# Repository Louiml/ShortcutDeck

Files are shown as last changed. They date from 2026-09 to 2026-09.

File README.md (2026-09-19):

# ShortcutDeck

A 6-button shortcut controller built on an Arduino Uno R3. Each button has its
own OLED label. A cross-platform Electron app on your PC customizes each button
to launch an app, file, or URL, or run a Lua script.

```
 OLED0  OLED1  OLED2         Arduino Uno R3
 [B0]   [B1]   [B2]   -+     +- TCA9548A (6x OLED I2C)
 OLED3  OLED4  OLED5   +USB- +-- 6x tactile buttons D2..D7
 [B3]   [B4]   [B5]   -+     +-- USB serial (115200)

 Electron companion app on your PC
 (GUI config + Lua sandbox + app launching)
```

## Repository layout

| Path | Purpose |
|---|---|
| `requirements.md` | Bill of materials, tools, system requirements |
| `circuit-schematic/`  | Wiring, schematic, component design, 3D case |
| `arduino/` | Firmware and serial protocol |
| `app/` | Electron companion app |

## Quick start

### 1. Electronics

Follow `circuit-schematic/wiring-diagram.md` to wire the Uno, TCA9548A, six
OLEDs, and six buttons. See `schematic.md` and `component-design.md` for layout,
power, and I2C addressing.

### 2. Firmware

Install the Adafruit SSD1306 and Adafruit GFX libraries. Open
`arduino/ShortcutDeck/ShortcutDeck.ino`, pick your port and board, and upload.
The deck sends `RDY` over serial at 115200 once it is up.

### 3. Companion app

```
cd app
npm install
npm start
```

Connect the deck, then edit and save button config. See `app/README.md`.

## Documentation

- `requirements.md` describes what to buy and install.
- `arduino/PROTOCOL.md` documents the serial protocol.
- `app/README.md` covers running the app, Lua scripting, and testing.

## License

MIT.

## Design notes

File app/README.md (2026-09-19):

# ShortcutDeck companion app

A cross-platform desktop app that works with the Arduino ShortcutDeck firmware.

## Features

- Configure all six buttons from one GUI.
  - Label shown on the button's OLED.
  - Icon (5 built-in glyphs, or none).
  - Action of none, launch (app, file, folder, or URL), or a Lua script.
- When the Arduino is connected, labels and icons push to the OLEDs automatically.
- Button presses arrive over USB serial and trigger the configured action.
- Lua scripts run sandboxed (via fengari) with a safe `deck` API.
- Config is saved locally and restored on each launch.

## Requirements

- Node.js 18+ for development.
- A CH340 driver if you use a clone Uno. Originals need none.

## Install and run

```
cd app
npm install
npm start
```

On some Linux systems the `serialport` native module needs build tools. `npm
install` usually fetches a prebuilt binary. If not, install `build-essential`
and `python3` and retry.

## Tests

```
npm test
```

This runs the Lua sandbox smoke test.

## Project layout

```
app/
|-- package.json
+-- src/
    |-- main/
    |   |-- main.js            Electron main process, IPC, wiring
    |   |-- configStore.js     persists button config to userData
    |   |-- serialManager.js   USB serial to the Arduino
    |   |-- luaRunner.js       sandboxed Lua execution (fengari)
    |   |-- launcher.js        cross-platform open and launch
    |   +-- test-lua.js        Lua sandbox smoke test
    +-- renderer/
        |-- index.html         GUI markup
        |-- style.css          GUI styling, dark theme
        +-- renderer.js        GUI logic and IPC calls
```

## Usage

1. Flash the Arduino. See `../arduino/ShortcutDeck/ShortcutDeck.ino`.
2. Plug in the Uno and launch the app.
3. In the Connect bar, pick the serial port and press Connect.
4. On connect, the current config pushes to the OLEDs (RDY handshake).
5. Edit any button card, then press Save & Apply to Deck.
6. Press a physical button. The app runs its action and logs it in the side
   panel.

## Lua scripting

Write Lua in any button with action set to Lua. The API:

```lua
deck.print("anything", 1, true)   -- log a line in the app log
deck.open("https://youtube.com")  -- open via the OS default handler
deck.exec("taskmgr.exe")          -- run a shell command, async
```

Sandbox restrictions:

- No `io`, `os.execute`, `os.exit`, filesystem, or network access.
- Only a curated global set is available: `table`, `string`, `math`, `os`
  (minus unsafe functions), `pairs`, `ipairs`, `pcall`, `error`, and so on.
- Scripts run on every button press.

## Notes

- Serial baud is fixed at 115200, matching the firmware.
- Labels cannot contain the pipe character. It is the protocol field separator.
- If you change the Lua code to reach the filesystem, you are expanding the
  sandbox. Keep it locked down.

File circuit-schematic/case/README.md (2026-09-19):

# Case design

Parametric OpenSCAD source: `deck_case.scad`

This renders a 2 by 3, two-piece snap-together enclosure.

- The top plate holds the six OLED windows and the six button bezels.
- The bottom base forms the cavity that holds the Arduino Uno, the TCA9548A
  breakout, and a rear USB opening.

## Files

| File | Description |
|---|---|
| `deck_case.scad` | Parametric source. Adjust the constants at the top. |
| `deck_case_top.stl` | Pre-rendered top plate. Open in a slicer. |
| `deck_case_bottom.stl`  | Pre-rendered bottom base. |

Ready-to-print STLs are included. To re-render after changing the source, use
the commands below. Adjust the OpenSCAD path if it is not in Program Files.

## Generating the STL files

You need [OpenSCAD](https://openscad.org/). Run this to export the parts:

```powershell
& "C:\Program Files\OpenSCAD\openscad.exe" deck_case.scad -D "part=0" -o deck_case_top.stl
& "C:\Program Files\OpenSCAD\openscad.exe" deck_case.scad -D "part=1" -o deck_case_bottom.stl
```

On macOS or Linux, adjust the path: `openscad deck_case.scad -D part=0 -o ...`.

## Print settings

- Material: PLA or PETG.
- Layer height: 0.2 mm.
- Infill: about 20%, with three or more top and bottom walls.
- Brim: recommended on the bottom base so the tall cavity walls stick.
- Orientation: print the top plate face down, floor up.

## Dimensions

| Item | Value |
|---|---|
| OLED breakout board | 27 by 27 by 9 mm recess|
| Visible OLED glass | 22 by 12 mm window |
| Tactile button | 12 mm diameter hole |
| Button pitch, X | 36 mm |
| Row pitch, Y | 42 mm |
| Case wall | 2.5 mm |
| Case height | 16 mm |
| USB-B port opening | 13 by 8 mm, rear wall  |

## Assembly

1. Drop each OLED in its top-plate recess, glass facing up. Tack it with a dab
   of hot glue or an M2 screw through the screw bosses.
2. Snip or place the tactile buttons so they stick through the 12 mm holes.
3. Wire everything to the Arduino (see `schematic.md`) and drop the Uno into the
   bottom cavity with its USB-B port lined up with the rear-wall opening, so the
   cable plugs in from outside.
4. Route the USB cable through the rear opening. Run six wires, SDA, SCL, 5V,
   GND, and VCC separately. Bussed headers are easier.
5. Snap the top over the bottom and secure the corners with M2 screws.

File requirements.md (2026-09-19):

# ShortcutDeck: requirements

A 6-button shortcut controller built on an Arduino Uno R3. Each button has its
own OLED label, customized from a cross-platform Electron app on the PC. Button
presses travel over USB serial to the PC, where a background app launches
apps, files, URLs, or runs user-written Lua scripts.

## Hardware

### Bill of materials

| # | Component | Qty | Notes | Est. cost |
|---|---|-----|---|---|
| 1 | Arduino Uno R3 | 1 | ATmega328P, 5V logic, 22 digital IO, 6 analog. | ~$25 |
| 2 | SSD1306 OLED 0.96" | 6 | I2C, address 0x3C. One per button. | ~$3 each  |
| 3 | TCA9548A I2C MUX | 1 | 8-channel I2C multiplexer. Selects which OLED to talk to. | ~$6 |
| 4 | Tactile push button  | 6 | 4-pin momentary switch, 12mm. | ~$0.20 |
| 5 | Resistor 10k ohm | 6 | Pull-down for each button. | ~$0.50 |
| 6 | Breadboard (830 pt)  | 1 | For prototyping. Optional if you solder to perfboard. | ~$4 |
| 7 | Jumper wires M-M | 1 | 20+ pieces, breadboard friendly. | ~$6 |
| 8 | USB A-B cable | 1 | Connects Uno to PC. Also supplies power and serial. | ~$3 |
| 9 | 3D-printed case | 1 | Optional enclosure. See `circuit-schematic/case/`. | filament  |

Total comes to about $60 to $75. You can start with a breadboard and a single
OLED to test the firmware before building all six.

### Power

- Uno USB provides 5V at 500mA (negotiated). All I2C devices are 3.3/5V tolerant.
- Each SSD1306 OLED draws roughly 15 to 25mA (20 to 30mA with backlight on).
  6 OLEDs worst case is about 120 to 150mA. That fits in the Uno USB budget.
- 6 buttons plus 6 pull-downs draw sub-milliamp, effectively nothing.
- Total draw is about 150 to 200mA. Safe on USB and on the Uno 5V regulator.

## Software and tools

| Tool | Purpose |
|---|---|
| Arduino IDE 1.8+  | Build and flash `ShortcutDeck.ino` |
| or Arduino CLI | Command-line build and flash |
| Node.js 18+ | Run the Electron app and install dependencies |
| npm | Install `electron`, `serialport`, `fengari` |
| Git | Version control |
| CH340 driver* | USB serial driver if you use a clone Uno |

*Original Arduino boards run an onboard ATmega16U2 and need no driver. Chinese
clones often use a CH340 chip and need the CH340 driver on Windows.

### Arduino libraries (Library Manager)

| Library | Purpose |
|---|---|
| Adafruit SSD1306 | SSD1306 OLED driver |
| Adafruit GFX | Graphics and text primitives for OLED |

The project cycles its own I2C channels instead of using the Adafruit
multiplexer library, to keep RAM low on the Uno's 2KB. See
`arduino/PROTOCOL.md` for details.

## I2C addressing

| Device | Address | Bus |
|---|---|---|
| TCA9548A multiplexer | 0x70 (configurable via A0-A2) | Main bus from Uno |
| Each SSD1306 OLED | 0x3C (all) | One of mux channels 0-5 |

All six OLEDs share address 0x3C because each sits on its own mux channel. You
do not need to solder address jumpers.

## System requirements

- Windows 10/11, macOS 11+, or Linux (X11/Wayland).
- Node.js 18+ is needed to run the app in development. Packaged Electron builds
  bundle Node, so end users do not need it.

## Functional requirements

1. Six physical buttons, each with an OLED showing its label and icon.
2. A button press sends `BTN:<index>` over USB serial.
3. The GUI app customizes each button:
   - Label text shown on the OLED.
   - Icon or emoji shown on the OLED.
   - Action type of launch (app/file/URL) or run a Lua script.
4. The app listens for button presses and triggers the configured action.
5. Lua scripts run in a sandboxed interpreter (fengari) with a small host API
   (open, exec, print). Scripts cannot reach the filesystem or network unless
   the bridge provides it.
6. The app saves config locally and pushes labels and icons to the Arduino, so
   the OLED labels survive restarts when the app runs.

## Out of scope for v1

- Audio routing or volume control. Could be added later as an action type.
- Multi-page button banks. The firmware only supports 6 buttons.
- Higher-resolution RGB LCDs. Would need an ESP32 or Mega.
- Hot-swapping pages over serial. Possible future feature.

## File map

```
ShortcutDeck/
|-- requirements.md
|-- circuit-schematic/
|   |-- wiring-diagram.md
|   |-- schematic.md
|   |-- component-design.md
|   +-- case/
|-- arduino/
|   |-- ShortcutDeck/ShortcutDeck.ino
|   +-- PROTOCOL.md
+-- app/
    +-- src/
        |-- main/
        +-- renderer/
```

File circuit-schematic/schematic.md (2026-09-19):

# Schematic

ASCII schematic of the ShortcutDeck electrical design.

## Block diagram

```
 Arduino Uno R3  - USB serial -  PC (Electron app)
                 |                receives BTN:n presses
                 |                sends OLED config
                 |
   I2C (SDA=A4, SCL=A5), 5V, GND
    |
    +-- 6 buttons (pull-downs) on D2..D7
    |
    +-- TCA9548A mux, channels 0-5
            |  |  |  |  |  |
          OLED0..5, one per channel, address 0x3C
```

## Full schematic

```
             ARDUINO UNO
                 5V ----+-----------------> 5V rail (OLEDs, buttons, mux)
                 GND ---+-----------------> GND rail
             A4 (SDA) --+->  TCA9548A.SDA
             A5 (SCL) --+->  TCA9548A.SCL
             D2 -> BTN0, pull-down -> GND
             D3 -> BTN1, pull-down -> GND
             D4 -> BTN2, pull-down -> GND
             D5 -> BTN3, pull-down -> GND
             D6 -> BTN4, pull-down -> GND
             D7 -> BTN5, pull-down -> GND

   TCA9548A:
     VCC GND SDA SCL  from Uno
     SD0 SC0 <-> OLED0 (0x3C)
     SD1 SC1 <-> OLED1 (0x3C)
     SD2 SC2 <-> OLED2 (0x3C)
     SD3 SC3 <-> OLED3 (0x3C)
     SD4 SC4 <-> OLED4 (0x3C)
     SD5 SC5 <-> OLED5 (0x3C)

   All six OLEDs share VCC and GND. Each OLED's SDA and SCL connect to one
   TCA9548A output pair, so they can all keep the default address 0x3C.
```

## Netlist

```
Net 5V:
   Uno.5V  -> TCA9548A.VCC, OLED0..5.VCC, BTN0..5.A

Net GND:
   Uno.GND -> TCA9548A.GND, OLED0..5.GND
            -> R0..R5 (10k pull-downs) -> BTN0..5 + D2..D7

Net I2C:
   Uno.A4 (SDA) -> TCA9548A.SDA
   Uno.A5 (SCL) -> TCA9548A.SCL

Net channel n (n = 0..5):
   TCA9548A.SDn -> OLEDn.SDA
   TCA9548A.SCn -> OLEDn.SCL

Net buttons:
   Uno.D2 -> R0 (to GND) + BTN0
   ... one per button, D3..D7 map to BTN1..BTN5
```

## Notes

Pull-ups. The TCA9548A breakout has onboard 4.7k ohm pull-ups on SDA and SCL.
If you use a bare mux chip, add your own. Each OLED branch adds none, so only
the main bus carries pull-ups.

Polarity. Some OLED modules run on 3.3V only. If yours is 5V tolerant it works
on the Uno. Most SSD1306 breakout boards accept 3.3V to 5V.

Addresses. The mux sits at 0x70 with A0, A1, and A2 all low. The OLEDs all sit
at 0x3C.

Reset. If your OLED has an RST pin, tie it high (5V) or leave it unconnected
when the module does not use it.

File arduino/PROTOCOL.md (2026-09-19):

# ShortcutDeck serial protocol

The Arduino and the Electron app talk over the Uno USB serial at 115200 baud.
Every message is ASCII text ended by a newline. A carriage return is ignored.

## Arduino to PC

| Message | Example | Meaning |
|---|---|---|
| `RDY` | `RDY` | Firmware booted, serial port is up |
| `BTN:<index>`  | `BTN:3` | Button index (0-5) was pressed |
| `OK` | `OK` | Command processed successfully |
| `ERR:<reason>` | `ERR:idx` | Command rejected (idx, cmd, argc, ...) |

`ERR` reasons:

| Reason  | Meaning |
|---|---|
| `empty` | empty line received |
| `cmd` | unknown command keyword |
| `argc`  | missing fields |
| `idx` | button index out of range (0-5) |
| `oledN` | display N failed to initialise |

## PC to Arduino

The app sends commands. The Arduino replies `OK` or `ERR:<reason>`.

| Command | Example | Meaning |
|---|---|---|
| `SET|<idx>|<icon>|<label>` | `SET|2|1|My Folder` | Set button idx label and icon |
| `CLEAR|<idx>` | `CLEAR|4` | Blank button idx (no icon or label)  |
| `PING` | `PING` | Liveness check |

### `SET` field details

- `<idx>` is a button index, an integer 0-5.
- `<icon>` is a glyph index, an integer 0-5. The mapping is:

  | Icon | Glyph   |
  |------|---------|
  | 0    | Play    |
  | 1    | Folder  |
  | 2    | Globe   |
  | 3    | Terminal|
  | 4    | Gear    |
  | 5    | Heart   |

  Use -1 for no icon.
- `<label>` is the rest of the line, up to 33 characters, shown on the OLED.
  Trailing whitespace and newlines are stripped. The label wraps to two centered
  lines on the display.

Labels may contain spaces but never the pipe character. Fields are separated by
a literal pipe, so do not put `|` in a label.

### Example exchange

```
PC -> A:  SET|0|0|YouTube
A -> PC:  OK
PC -> A:  SET|5|-1|Notes
A -> PC:  OK
A -> PC:  BTN:0        user pressed button 0
...
A -> PC:  BTN:5
PC -> A:  PING
A -> PC:  OK
```

## Notes

- Baud is fixed at 115200 in `ShortcutDeck.ino`.
- The Arduino sends `RDY` about 200 ms after boot. The app should wait for it
  before pushing config.
- Messages are small and line-buffered, so no length-prefix framing is needed.

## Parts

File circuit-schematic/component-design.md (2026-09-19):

# Component design

Layout, power budget, I2C addressing, and firmware RAM strategy for the
ShortcutDeck.

## Physical layout

A 2 by 3 grid of buttons, each with an OLED above it.

```
ShortcutDeck case
  OLED0 OLED1 OLED2       row 1 OLEDs
  B0    B1    B2          row 1 buttons
  OLED3 OLED4 OLED5       row 2 OLEDs
  B3    B4    B5          row 2 buttons
```

The Arduino, or a small perfboard with the TCA9548A, sits in the bottom of the
enclosure. A USB-B hole in the back routes the cable out.

## Power

| Load | Current |
|---|---|
| 6 SSD1306 | about 120mA |
| 6 buttons plus resistors | under 1mA |
| Arduino board | about 50mA idle  |
| TCA9548A | about 0.1mA |
| Total | about 170-200mA  |

That sits well below the Uno 500mA USB budget, so no external supply is needed.

Do not put anything else on the 5V rail that draws over 300mA total. If you add
LED backlights, budget them separately. All I2C lines stay on the 5V bus with a
shared ground.

## I2C multiplexer

The mux takes over the main bus and fans out to eight channels. We use 0 through
5.

- Main bus: Uno A4/A5 to TCA9548A SDA/SCL.
- The mux answers at 0x70 with A0, A1, and A2 grounded.
- The firmware writes one byte to the mux. Bit n set to 1 selects channel n.
- To update OLED 3, write 0x08 (channel 3) to address 0x70, then talk to the
  SSD1306 at 0x3C.
- All six OLEDs keep address 0x3C. The mux isolates each channel, so repeated
  addresses across different channels work.

Selecting channel n means calling `Wire.write(1 << n)` to address 0x70.

## Firmware RAM

The Uno has 2KB of SRAM. A full SSD1306 framebuffer is 1KB (128x64x1 bit). Six
of them would be 6KB, which will not fit. The firmware reuses one shared buffer
and cycles it across the channels, refreshing each OLED in its own time slice.

```
loop:
  for channel in 0..5:
    mux.select(channel)
    oled.drawBuffer(shared_buffer)   one reused 1KB buffer
    oled.display()
```

Because the labels and icons are static, the refresh rate does not matter. Total
RAM stays under 2KB: one 1KB buffer plus six short label strings.

If you move to an ESP32 (520KB RAM) or Mega (8KB), you can keep six independent
framebuffers and render icons or images freely.

## Icon and label rendering

Each OLED is 128 by 64 pixels.

- Row 1, pixels 0-24, holds the icon. Either a large character or a small bitmap
  glyph.
- Row 2, pixels 26-64, holds up to three lines of wrapped label text.

The firmware stores a label string and an icon per button. If the user supplies
an emoji, the default bitmap font cannot render it, since there is no unicode
glyph. The app instead picks from a set of built-in glyph bitmaps or a plain
character. See the GUI notes.

The firmware ships 24 by 24 mono glyphs for play, folder, globe, terminal, gear,
and heart, selected by index 0 through 5. The app maps the user choice to that
index and sends it over serial.

## Serial protocol summary

See `arduino/PROTOCOL.md` for the full reference. Messages are ASCII and ended
by a newline.

| Direction | Format | Purpose |
|---|---|---|
| Arduino to PC | `BTN:<0-5>` | Button pressed |
| Arduino to PC | `RDY` | Firmware ready on boot |
| Arduino to PC | `OK` / `ERR:<reason>` | Command acknowledgement |
| PC to Arduino | `SET|<idx>|<icon>|<label>` | Configure OLED label/icon  |
| PC to Arduino | `CLEAR|<idx>` | Blank an OLED |
| PC to Arduino | `PING` | Liveness check, replies OK  |

Labels are plain text. `<icon>` is an integer glyph index 0-5, or -1 for none.

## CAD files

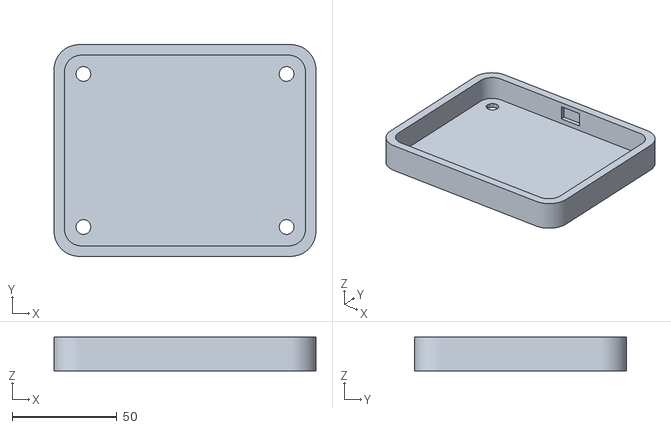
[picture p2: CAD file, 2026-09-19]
circuit-schematic/case/deck_case_bottom.stl
125.0 x 101.0 x 16.0

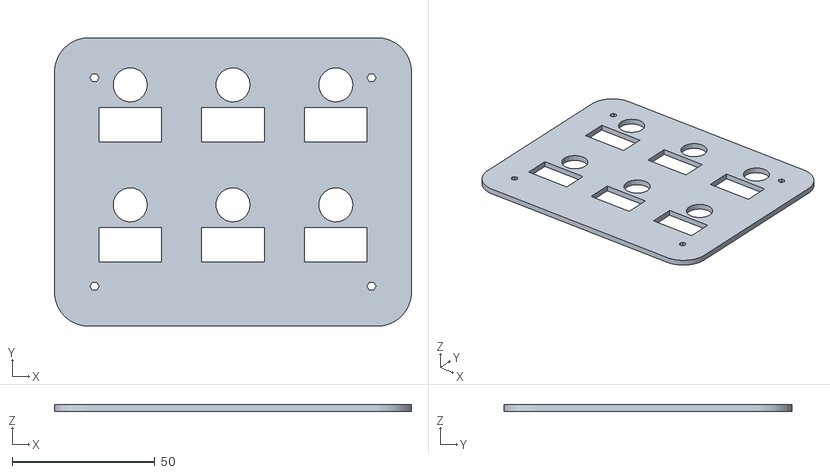
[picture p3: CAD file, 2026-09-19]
circuit-schematic/case/deck_case_top.stl
125.0 x 101.0 x 2.50

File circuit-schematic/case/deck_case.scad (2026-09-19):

deck_cols = 3;
deck_rows = 2;
spacing_x = 36;
spacing_y = 42;
oled_w    = 27;
oled_h    = 27;
glass_w   = 22;
glass_h   = 12;
btn_dia   = 12;
btn_inset = 4;

case_wall = 2.5;
case_h    = 16;
oled_ch   = 9;
btn_ch    = 4;
wall_tol  = 0.3;
screw_r   = 1.6;
screw_dx  = 8;
screw_dy  = 8;

usb_w     = 13;
usb_h     = 8;
usb_from_floor = 3;
usb_recess     = 8;

unit_cw   = spacing_x;
unit_rowA = 20;
unit_rowB = 34;
inner_w   = deck_cols * spacing_x + case_wall * 2;
inner_h   = deck_rows * spacing_y + case_wall * 2;

module rounded_square(w, h, r, $fn=48) {
    hull() {
        for (x = [r, w-r]) for (y = [r, h-r])
            translate([x, y, 0]) circle(r=r);
    }
}

module top_plate() {
    difference() {
        linear_extrude(case_wall)
            offset(r=6) rounded_square(inner_w, inner_h, 6);
        for (c=[0:deck_cols-1]) for (r=[0:deck_rows-1]) {
            let(x = case_wall + (c+0.5)*spacing_x,
                y = case_wall + r*spacing_y + unit_rowA) {
                translate([x - glass_w/2, y - glass_h/2, 0])
                    cube([glass_w, glass_h, case_wall+1]);
                translate([x - oled_w/2, y - oled_h/2, case_wall])
                    linear_extrude(oled_ch)
                        rounded_square(oled_w, oled_h, 2);
            }
        }
        for (c=[0:deck_cols-1]) for (r=[0:deck_rows-1]) {
            let(x = case_wall + (c+0.5)*spacing_x,
                y = case_wall + r*spacing_y + unit_rowB)
                translate([x, y, 0]) cylinder(d=btn_dia, h=case_wall+btn_ch+1);
        }
        for (x=[screw_dx, inner_w-screw_dx])
            for (y=[screw_dy, inner_h-screw_dy])
                translate([x, y, -1]) cylinder(d=screw_r*2, h=case_wall+3);
    }
}

module bottom_base() {
    difference() {
        union() {
            translate([0, 0, 0])
                linear_extrude(case_h - case_wall)
                    offset(r=6) rounded_square(inner_w, inner_h, 6);
            linear_extrude(case_h)
                offset(r=6) rounded_square(inner_w, inner_h, 6);
        }
        translate([case_wall+0.5, case_wall+0.5, case_wall])
            linear_extrude(case_h)
                offset(r=4) rounded_square(
                    inner_w-2*case_wall-1, inner_h-2*case_wall-1, 4);
        for (x=[screw_dx, inner_w-screw_dx])
            for (y=[screw_dy, inner_h-screw_dy])
                translate([x, y, -1]) cylinder(d=screw_r*2 + 4, h=case_h+2);
        let(ux = inner_w/2 - usb_w/2,
            uy = inner_h - usb_recess,
            uz = case_wall + usb_from_floor) {
            translate([ux, uy, uz])
                cube([usb_w, usb_recess + case_wall + 1, usb_h]);
        }
    }
}

part = 1;
if (part == 0) top_plate();
else           bottom_base();

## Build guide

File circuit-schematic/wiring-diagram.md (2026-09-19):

# Wiring diagram

Pin-by-pin wiring table for the ShortcutDeck.

## Uno to TCA9548A (main I2C bus)

| Uno pin | Function  | TCA9548A pin | Notes |
|---|---|---|---|
| A5 (SCL) D19 | I2C clock | SCL | Connect A5 to SCL. Pull-ups live on the mux board. |
| A4 (SDA) D18 | I2C data  | SDA | Connect A4 to SDA. |
| 5V | Power | VCC | 5V supply to the mux and OLEDs. |
| GND | Ground | GND | Shared ground. |

The TCA9548A breakout board usually carries onboard pull-up resistors for SDA
and SCL. If you use a bare chip, add two 4.7k ohm pull-ups, one from SDA to VCC
and one from SCL to VCC. Do not add duplicate pull-ups on each OLED branch.

## TCA9548A to 6 OLEDs

Each OLED has its own mux channel. They all share the same wiring.

| Channel | OLED | Button | Connection |
|---|---|---|---|
| SD0 / SC0 | OLED 0 | Button 0 | VCC to VCC, GND to GND, SDA to SD0, SCL to SC0 |
| SD1 / SC1 | OLED 1 | Button 1 | VCC to VCC, GND to GND, SDA to SD1, SCL to SC1 |
| SD2 / SC2 | OLED 2 | Button 2 | VCC to VCC, GND to GND, SDA to SD2, SCL to SC2 |
| SD3 / SC3 | OLED 3 | Button 3 | VCC to VCC, GND to GND, SDA to SD3, SCL to SC3 |
| SD4 / SC4 | OLED 4 | Button 4 | VCC to VCC, GND to GND, SDA to SD4, SCL to SC4 |
| SD5 / SC5 | OLED 5 | Button 5 | VCC to VCC, GND to GND, SDA to SD5, SCL to SC5 |

Per OLED pin (SSD1306 breakout):

| OLED pin | Connect to |
|---|---|
| VCC | 5V, the shared bus line |
| GND | GND, shared |
| SDA | That channel's SDx pin on TCA9548A |
| SCL | That channel's SCx pin on TCA9548A |

## Uno to 6 buttons (10k ohm pull-down)

Each button uses a digital input plus an external 10k ohm pull-down, so the pin
reads LOW normally and HIGH only while pressed.

| Button | Uno digital pin | One leg to | Other leg to | 10k ohm pull-down  |
|---|---|---|---|---|
| 0 | D2 | VCC (5V) | D2 | D2 to GND |
| 1 | D3 | VCC (5V) | D3 | D3 to GND |
| 2 | D4 | VCC (5V) | D4 | D4 to GND |
| 3 | D5 | VCC (5V) | D5 | D5 to GND |
| 4 | D6 | VCC (5V) | D6 | D6 to GND |
| 5 | D7 | VCC (5V) | D7 | D7 to GND |

For a 4-pin tactile switch, the two legs on one side are connected internally.
Use one leg of side A for 5V and one leg of side B for the digital pin. The 10k
ohm resistor connects the digital pin to GND.

### Shared 5V rail

All six buttons can share one 5V bus line from the Uno 5V pin instead of six
separate wires back to the board. Route 5V to the left legs of all buttons, and
each right leg to its digital pin plus pull-down to GND.

## Uno pin map

```
        D2  -> Button 0
        D3  -> Button 1
        D4  -> Button 2
        D5  -> Button 3
        D6  -> Button 4
        D7  -> Button 5
        A4 (D18) = SDA  -> I2C data
        A5 (D19) = SCL  -> I2C clock
        5V             -> OLEDs, buttons, mux
        GND            -> ground rail
```

The firmware uses A4/D18 as SDA and A5/D19 as SCL for I2C.

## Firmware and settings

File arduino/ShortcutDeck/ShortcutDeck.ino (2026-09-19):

#include <Wire.h>
#include <Adafruit_GFX.h>
#include <Adafruit_SSD1306.h>
#include <stdarg.h>
#include <string.h>
#include <stdlib.h>

#define NUM_BUTTONS    6
#define NUM_OLEDS      6
const uint8_t BTN_PINS[NUM_BUTTONS] = {2, 3, 4, 5, 6, 7};

#define MUX_ADDR       0x70
#define OLED_ADDR      0x3C
#define SCREEN_W       128
#define SCREEN_H       64
#define DEBOUNCE_MS    25
#define LONG_MS        500

#define BUF_H          64

Adafruit_SSD1306 display(SCREEN_W, SCREEN_H, &Wire, -1);

static const uint16_t GLYPH_PLAY[16] = {
    0x0010,0x0030,0x0070,0x00F0,0x01F0,0x03F0,0x07F0,0x0FF0,
    0x01F0,0x03F0,0x0070,0x00F0,0x01F0,0x0030,0x0070,0x0010
};
static const uint16_t GLYPH_FOLDER[16] = {
    0x01FF,0x0200,0x0200,0x03FF,0x0400,0x0800,0x0800,0x0800,
    0x0800,0x0800,0x0800,0x0800,0x0800,0x0800,0x0FFF,0x0000
};
static const uint16_t GLYPH_GLOBE[16] = {
    0x0000,0x07E0,0x0FF0,0x1FF8,0x3FFC,0x7FFE,0x7E7E,0xFE7F,
    0xFE7F,0x7E7E,0x7FFE,0x3FFC,0x1FF8,0x0FF0,0x07E0,0x0000
};
static const uint16_t GLYPH_TERM[16] = {
    0x0000,0x1FFF,0x3FFF,0x3FFF,0x3F00,0x3F00,0x3F00,0x3F00,
    0x3F00,0x3F00,0x3F00,0x3F00,0x3F00,0x3F00,0x3FFF,0x0000
};
static const uint16_t GLYPH_GEAR[16] = {
    0x03C0,0x0660,0x1E78,0x3FFC,0x3FFC,0x7FFE,0x7FFE,0x7FFE,
    0x7FFE,0x7FFE,0x7FFE,0x3FFC,0x3FFC,0x1E78,0x0660,0x03C0
};
static const uint16_t GLYPH_HEART[16] = {
    0x0000,0x0E70,0x1FF8,0x3FFC,0x3FFC,0x3FFC,0x3FFC,0x3FFC,
    0x1FF8,0x1FF8,0x0FF0,0x07E0,0x03C0,0x0180,0x0000,0x0000
};
static const uint16_t* GLYPHS[6] = {
    GLYPH_PLAY, GLYPH_FOLDER, GLYPH_GLOBE,
    GLYPH_TERM, GLYPH_GEAR,   GLYPH_HEART
};

struct ButtonCfg {
    int8_t  icon;
    char    label[34];
};
static ButtonCfg cfg[NUM_BUTTONS];

static bool     lastState[NUM_BUTTONS];
static uint32_t lastDebounce[NUM_BUTTONS];

static char rxBuf[96];
static uint8_t rxLen;

static void muxSelect(uint8_t ch) {
    Wire.beginTransmission(MUX_ADDR);
    Wire.write(1 << ch);
    Wire.endTransmission();
}

static void renderOled(uint8_t ch) {
    muxSelect(ch);
    display.clearDisplay();

    int8_t icon = cfg[ch].icon;
    if (icon >= 0 && icon < 6) {
        int x = (SCREEN_W - 16) / 2;
        display.fillRect(x - 4, 4, 24, 24, SSD1306_BLACK);
        for (uint8_t row = 0; row < 16; row++) {
            uint16_t bits = GLYPHS[icon][row];
            for (uint8_t b = 0; b < 16; b++) {
                if (bits & (1 << b)) {
                    display.drawPixel(x + b, 4 + row, SSD1306_WHITE);
                }
            }
        }
    }

    display.setTextColor(SSD1306_WHITE);
    display.setTextSize(1);
    char *label = cfg[ch].label;
    if (label[0] == '\0') {
        display.setCursor(0, 52);
        display.println("-");
    } else {
        display.setCursor(0, 38);
        int line1len = 0;
        for (const char *p = label; *p && line1len < 16; p++) {
            line1len++;
        }
        char line1[17], line2[17];
        memcpy(line1, label, line1len);
        line1[line1len] = '\0';
        int i = line1len;
        int l2 = 0;
        while (label[i] && l2 < 16) { line2[l2++] = label[i++]; }
        line2[l2] = '\0';
        int cx1 = (SCREEN_W - line1len * 6) / 2;
        display.setCursor(cx1 > 0 ? cx1 : 0, 38);
        display.print(line1);
        if (l2 > 0) {
            int cx2 = (SCREEN_W - l2 * 6) / 2;
            display.setCursor(cx2 > 0 ? cx2 : 0, 52);
            display.print(line2);
        }
    }

    display.display();
}

static void renderAll() {
    for (uint8_t i = 0; i < NUM_OLEDS; i++) renderOled(i);
}

static void sendLine(const char *fmt, ...) {
    char tmp[96];
    va_list args;
    va_start(args, fmt);
    vsnprintf(tmp, sizeof(tmp), fmt, args);
    va_end(args);
    Serial.print(tmp);
    Serial.print("\r\n");
}

static void handleLine(char *line) {
    char *tok = strtok(line, "|");
    if (!tok) { sendLine("ERR:empty"); return; }

    if (strcmp(tok, "PING") == 0) {
        sendLine("OK");
    } else if (strcmp(tok, "CLEAR") == 0) {
        char *idxS = strtok(NULL, "|");
        if (!idxS) { sendLine("ERR:argc"); return; }
        int idx = atoi(idxS);
        if (idx < 0 || idx >= NUM_BUTTONS) { sendLine("ERR:idx"); return; }
        cfg[idx].icon = -1;
        cfg[idx].label[0] = '\0';
        renderOled((uint8_t)idx);
        sendLine("OK");
    } else if (strcmp(tok, "SET") == 0) {
        char *idxS = strtok(NULL, "|");
        char *iconS = strtok(NULL, "|");
        char *label = strtok(NULL, "");
        if (!idxS || !iconS) { sendLine("ERR:argc"); return; }
        int idx = atoi(idxS);
        if (idx < 0 || idx >= NUM_BUTTONS) { sendLine("ERR:idx"); return; }
        int icon = atoi(iconS);
        cfg[idx].icon = (icon < 0 || icon >= 6) ? -1 : icon;
        if (label) {
            size_t n = strlen(label);
            while (n > 0 && (label[n-1]=='\n'||label[n-1]=='\r'||label[n-1]==' ')) {
                label[--n] = '\0';
            }
            if (n >= sizeof(cfg[idx].label)) n = sizeof(cfg[idx].label) - 1;
            memcpy(cfg[idx].label, label, n);
            cfg[idx].label[n] = '\0';
        } else {
            cfg[idx].label[0] = '\0';
        }
        renderOled((uint8_t)idx);
        sendLine("OK");
    } else {
        sendLine("ERR:cmd");
    }
}

static void pollSerial() {
    while (Serial.available()) {
        char c = Serial.read();
        if (c == '\n' || c == '\r') {
            if (rxLen > 0) {
                rxBuf[rxLen] = '\0';
                handleLine(rxBuf);
                rxLen = 0;
            }
            continue;
        }
        if (rxLen < sizeof(rxBuf) - 1) {
            rxBuf[rxLen++] = c;
        } else {
            rxLen = 0;
        }
    }
}

static void pollButtons() {
    for (uint8_t i = 0; i < NUM_BUTTONS; i++) {
        bool reading = digitalRead(BTN_PINS[i]) == HIGH;
        if (reading != lastState[i]) {
            lastDebounce[i] = millis();
            lastState[i] = reading;
        }
        if (reading && lastState[i] && (millis() - lastDebounce[i] >= DEBOUNCE_MS)) {
            static uint32_t lastSent[NUM_BUTTONS];
            if (millis() - lastSent[i] > 50) {
                lastSent[i] = millis();
                sendLine("BTN:%d", i);
            }
            delay(1);
        }
    }
}

void setup() {
    memset(&cfg, 0, sizeof(cfg));
    for (uint8_t i = 0; i < NUM_BUTTONS; i++) {
        cfg[i].icon = -1;
        cfg[i].label[0] = '\0';
        pinMode(BTN_PINS[i], INPUT);
        lastState[i] = false;
        lastDebounce[i] = 0;
    }

    Serial.begin(115200);
    delay(200);
    sendLine("RDY");

    Wire.begin();
    Wire.setClock(400000);

    for (uint8_t i = 0; i < NUM_OLEDS; i++) {
        muxSelect(i);
        if (!display.begin(SSD1306_SWITCHCAPVCC, OLED_ADDR)) {
            sendLine("ERR:oled%d", i);
        }
        display.clearDisplay();
    }
    renderAll();
}

void loop() {
    pollSerial();
    pollButtons();
}
